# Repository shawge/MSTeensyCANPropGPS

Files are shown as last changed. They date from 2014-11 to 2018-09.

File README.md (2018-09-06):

# MSTeensyCANPropGPS
This project uses a Teensy 3.2 microcontroller to exchange data with a MegaSquirt MS3Pro engine controller over a CAN bus.

## Hardware used
* [Teensy 3.2 microcontroller](https://www.pjrc.com/store/teensy32.html)
* [Teensy Prop Shield](https://www.pjrc.com/store/prop_shield.html) connected via SPI and I2C.
  * 6-axis sensor, linear accelerometer and magnetometer
  * 3-axis angular rate gyroscope
  * Pressure/altitude and temperature
  * 2 watt audio amp
  * High speed 5V buffers for driving LEDs
  * 8MB flash
* [Adafruit Ultimate GPS](http://www.adafruit.com/products/746) connected via serial
  * Version 3, 66 channel w/ 10Hz updates
* [Waveshare CAN Transceiver](https://www.waveshare.com/sn65hvd230-can-board.htm) connected via serial
* [Color 320x240 TFT Touch Screen](https://www.pjrc.com/store/display_ili9341_touch.html) connected via SPI

## Libraries used
* [NXPMotionSense](https://github.com/PaulStoffregen/NXPMotionSense) - motion sensors
* [ILI9341_t3](https://github.com/PaulStoffregen/ILI9341_t3) - TFT
* [XPT2046_Touchscreen](https://github.com/PaulStoffregen/XPT2046_Touchscreen) - touch screen
* [FlexCAN](https://github.com/teachop/FlexCAN_Library) - CAN bus
* [TinyGPSPlus](https://github.com/mikalhart/TinyGPSPlus) - GPS
* [FastLED](https://github.com/FastLED/FastLED) - LED

## Inspiration for this project is from 
* openhoon/MSCan_Gauge
* merkur2k/MSCan_Gauge

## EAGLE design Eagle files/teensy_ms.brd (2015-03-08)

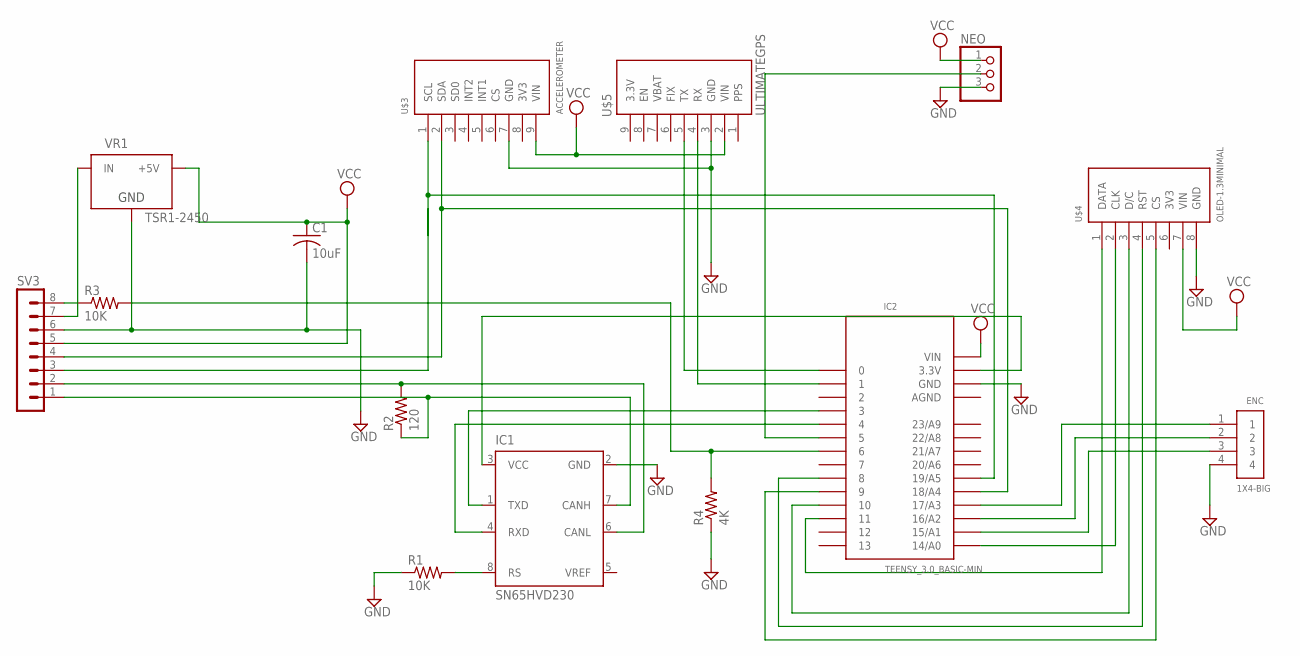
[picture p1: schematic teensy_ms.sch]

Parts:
C1: 10uF; C1206
ENC: 1X4-BIG; 1X04-BIG
IC1: SN65HVD230; SO8
IC2: TEENSY_3.0_BASIC-MIN; TEESNY_3.0_BASIC-MIN
NEO: PINHD-1X3; 1X03
R1, R3: 10K; M1206
R2: 120; M1206
R4: 4K; M1206
SV3: MA08-1
U$3: ACCELEROMETER
U$4: OLED-1.3MINIMAL; OLED-1.3-BARE
U$5: ULTIMATEGPS
VR1: TSR1-2450; TSR-1

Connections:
AGND: IC2.AGND
GND: C1.2, ENC.4, IC1.2 (GND), IC2.GND, NEO.3, R1.1, R4.1, SV3.6, U$3.7 (GND), U$4.8 (GND), U$5.3 (GND), VR1.2 (GND)
unnamed: IC1.8 (RS), R1.2
unnamed: IC1.3 (VCC), IC2.3.3V
unnamed: SV3.7, VR1.1 (IN)
unnamed: IC2.1, U$5.4 (RX)
unnamed: IC2.0, U$5.5 (TX)
unnamed: IC2.11, U$4.1 (DATA)
unnamed: IC2.14/A0, U$4.2 (CLK)
unnamed: IC2.10, U$4.3 (D/C)
unnamed: IC2.8, U$4.4 (RST)
unnamed: IC2.9, U$4.5 (CS)
unnamed: IC1.4 (RXD), IC2.4
unnamed: IC2.19/A5, SV3.3, U$3.1 (SCL)
unnamed: IC1.1 (TXD), IC2.3
unnamed: IC2.18/A4, SV3.4, U$3.2 (SDA)
unnamed: IC2.5, NEO.2
unnamed: IC1.7 (CANH), R2.1, SV3.1
unnamed: IC2.6, R3.2, R4.2
unnamed: IC1.6 (CANL), R2.2, SV3.2
unnamed: ENC.3, IC2.15/A1
unnamed: ENC.2, IC2.16/A2
unnamed: ENC.1, IC2.17/A3
unnamed: R3.1, SV3.8
VCC: C1.1, IC2.VIN, NEO.1, SV3.5, U$3.9 (VIN), U$4.7 (VIN), U$5.2 (VIN), VR1.3 (+5V)

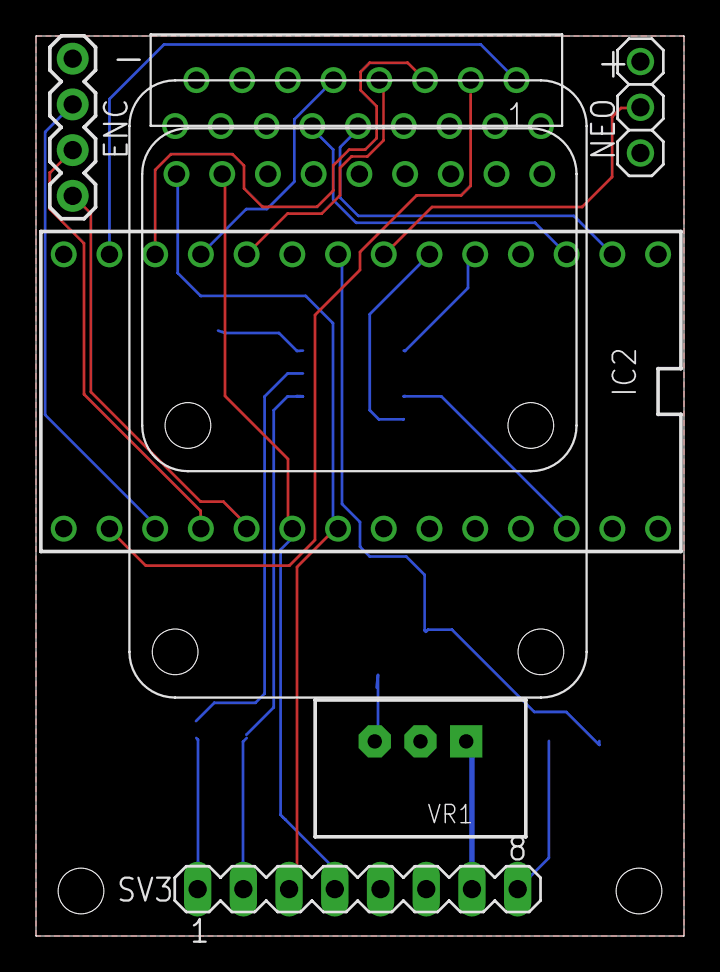
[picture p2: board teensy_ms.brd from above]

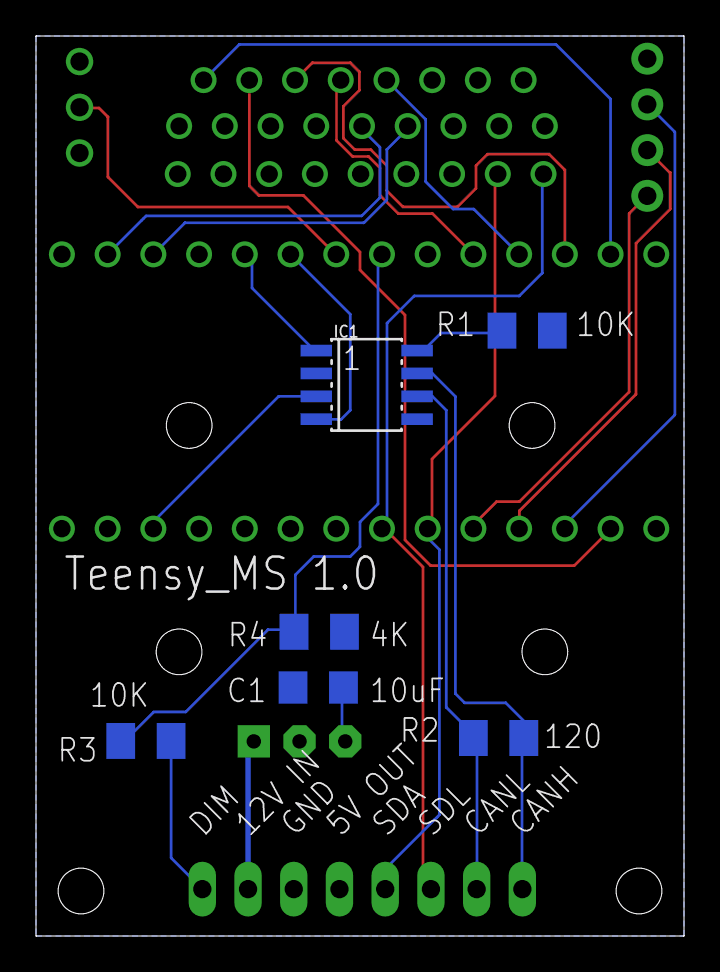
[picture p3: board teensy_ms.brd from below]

Board: 2 copper layers, 36.0 x 50.0 mm, 14 parts (6 on the bottom side), 24 nets.

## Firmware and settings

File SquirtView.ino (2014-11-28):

/*
  Although heavily modified by now to work with the Teensy and with newer Megasquirt features
  (CAN broadcasting), much of this code originally came from https://github.com/kckr/MSCan_Gauge
  Many thanks to that project, as I would not have gotten started without it.
*/

// User configuerable variables
const int myCANid = 10; // CAN ID of this unit
const int msCANid = 0; // CAN ID of the Megasquirt (should almost always be 0)
const int REVLIMIT = 6800; // soft rev limit at which to start blinking the tach gauge

#include <Metro.h>
#include <FlexCAN.h>
#include <SPI.h>
#include <Wire.h>
#include <Adafruit_GFX.h>
#include <Adafruit_SSD1306.h>
#include <Time.h>
#include <TinyGPS++.h>
TinyGPSPlus GPS;

#include <FastLED.h>
#define LEDPIN 5
#define NUMLEDS 16
CRGB leds[NUMLEDS];

#include <Encoder.h>
Encoder myEnc(7, 6); // interrupts on pin6, 7
#define RBUTTON_INT 15 // pin 15
const unsigned long debouncing_time = 150; //Debouncing Time - 150 is good, 200 is better, 250 seems worse
volatile unsigned long last_millis; //switch debouncing

#include <Adafruit_Sensor.h>
#include <Adafruit_ADXL345_U.h>
/* Assign a unique ID to this sensor at the same time */
Adafruit_ADXL345_Unified accel = Adafruit_ADXL345_Unified(12345);

// OLED display
/* Software SPI
#define OLED_MOSI   9
#define OLED_CLK   10
#define OLED_DC    11
#define OLED_CS    12
#define OLED_RESET 8
Adafruit_SSD1306 display(OLED_MOSI, OLED_CLK, OLED_DC, OLED_RESET, OLED_CS);
*/

// Hardware SPI
#define OLED_DC     10
#define OLED_CS     9
#define OLED_RESET  8
Adafruit_SSD1306 display(OLED_DC, OLED_RESET, OLED_CS);

#if (SSD1306_LCDHEIGHT != 64)
#error("Height incorrect, please fix Adafruit_SSD1306.h!");
#endif

// Metro ticks are milliseconds
Metro gpsTimer = Metro(1000); // display GPS status
Metro commTimer = Metro(1000); // display an error message if no CAN data during this interval
Metro displayTimer = Metro(100); // refresh the display at this interval
Metro ledTimer = Metro(1); // how long to flash the led upon CAN frame receive/transmit
Metro gaugeBlinkTimer = Metro(100); // blink the led ring pixels during certain conditions
boolean connectionState = false;
boolean gpsLogo = false;
boolean gaugeBlink = false;

int led = 13;
FlexCAN CANbus(500000);
static CAN_message_t txmsg,rxmsg;
static uint8_t hex[17] = "0123456789abcdef";

int rpm,ect,afr;
unsigned int txTimer,rxTimer;

//MS data vars
byte indicator[7]; // where to store indicator data
unsigned int RPM, CLT, MAP, MAT, SPKADV, BATTV, TPS, Knock, Baro, EGOc, IAC, dwell, bstduty, idle_tar;
int AFR, AFRtgt;
unsigned int MAP_HI, Knock_HI, RPM_HI, CLT_HI, MAT_HI;
int AFR_HI, AFR_LO;

//static char sprintfbuffer[2];

struct ledval {
  byte r0;
  byte g0;
  byte b0;
  byte r1;
  byte g1;
  byte b1;
  byte r2;
  byte g2;
  byte b2;
  byte r3;
  byte g3;
  byte b3;
};

const ledval ledarray[] PROGMEM = {
//r0, g0, b0, r1, g1, b1, r2, g2, b2, r3, g3, b3
  {0x0,0x5,0xFF,0x0,0x0,0x0,0x0,0x0,0x0,0x0,0x0,0x0}, //0
  {0x0,0x6,0xFE,0x0,0x0,0x0,0x0,0x0,0x0,0x0,0x0,0x0}, //1
  {0x0,0x7,0xFD,0x0,0x0,0x0,0x0,0x0,0x0,0x0,0x0,0x0}, //2
  {0x0,0x8,0xFC,0x0,0x0,0x0,0x0,0x0,0x0,0x0,0x0,0x0}, //3
  {0x0,0x9,0xFB,0x0,0x0,0x0,0x0,0x0,0x0,0x0,0x0,0x0}, //4
  {0x0,0xA,0xFA,0x0,0x0,0x0,0x0,0x0,0x0,0x0,0x0,0x0}, //5
  {0x0,0xB,0xF9,0x0,0x0,0x0,0x0,0x0,0x0,0x0,0x0,0x0}, //6
  {0x0,0xC,0xF8,0x0,0x0,0x0,0x0,0x0,0x0,0x0,0x0,0x0}, //7
  {0x0,0xD,0xF7,0x0,0x0,0x0,0x0,0x0,0x0,0x0,0x0,0x0}, //8
  {0x0,0xE,0xF6,0x0,0x0,0x0,0x0,0x0,0x0,0x0,0x0,0x0}, //9
  {0x0,0xF,0xF5,0x0,0x0,0x0,0x0,0x0,0x0,0x0,0x0,0x0}, //10
  {0x0,0x10,0xF4,0x0,0x0,0x0,0x0,0x0,0x0,0x0,0x0,0x0}, //11
  {0x0,0x11,0xF3,0x0,0x0,0x0,0x0,0x0,0x0,0x0,0x0,0x0}, //12
  {0x0,0x12,0xF2,0x0,0x0,0x0,0x0,0x0,0x0,0x0,0x0,0x0}, //13
  {0x0,0x13,0xF1,0x0,0x0,0x0,0x0,0x0,0x0,0x0,0x0,0x0}, //14
  {0x0,0x14,0xF0,0x0,0x0,0x0,0x0,0x0,0x0,0x0,0x0,0x0}, //15
  {0x0,0x15,0xEF,0x0,0x0,0x0,0x0,0x0,0x0,0x0,0x0,0x0}, //16
  {0x0,0x16,0xEE,0x0,0x0,0x0,0x0,0x0,0x0,0x0,0x0,0x0}, //17
  {0x0,0x17,0xED,0x0,0x0,0x0,0x0,0x0,0x0,0x0,0x0,0x0}, //18
  {0x0,0x18,0xEC,0x0,0x0,0x0,0x0,0x0,0x0,0x0,0x0,0x0}, //19
  {0x0,0x19,0xEB,0x0,0x0,0x0,0x0,0x0,0x0,0x0,0x0,0x0}, //20
  {0x0,0x1A,0xEA,0x0,0x0,0x0,0x0,0x0,0x0,0x0,0x0,0x0}, //21
  {0x0,0x1B,0xE9,0x0,0x0,0x0,0x0,0x0,0x0,0x0,0x0,0x0}, //22
  {0x0,0x1C,0xE8,0x0,0x0,0x0,0x0,0x0,0x0,0x0,0x0,0x0}, //23
  {0x0,0x1D,0xE7,0x0,0x0,0x0,0x0,0x0,0x0,0x0,0x0,0x0}, //24
  {0x0,0x1E,0xE6,0x0,0x0,0x0,0x0,0x0,0x0,0x0,0x0,0x0}, //25
  {0x0,0x1F,0xE5,0x0,0x0,0x0,0x0,0x0,0x0,0x0,0x0,0x0}, //26
  {0x0,0x20,0xE4,0x0,0x0,0x0,0x0,0x0,0x0,0x0,0x0,0x0}, //27
  {0x0,0x21,0xE3,0x0,0x0,0x0,0x0,0x0,0x0,0x0,0x0,0x0}, //28
  {0x0,0x22,0xE2,0x0,0x0,0x0,0x0,0x0,0x0,0x0,0x0,0x0}, //29
  {0x0,0x23,0xE1,0x0,0x0,0x0,0x0,0x0,0x0,0x0,0x0,0x0}, //30
  {0x0,0x24,0xE0,0x0,0x0,0x0,0x0,0x0,0x0,0x0,0x0,0x0}, //31
  {0x0,0x25,0xDF,0x0,0x0,0x0,0x0,0x0,0x0,0x0,0x0,0x0}, //32
  {0x0,0x26,0xDE,0x0,0x0,0x0,0x0,0x0,0x0,0x0,0x0,0x0}, //33
  {0x0,0x27,0xDD,0x0,0x0,0x1,0x0,0x0,0x0,0x0,0x0,0x0}, //34
  {0x0,0x28,0xDC,0x0,0x0,0x1,0x0,0x0,0x0,0x0,0x0,0x0}, //35
  {0x0,0x29,0xDB,0x0,0x0,0x1,0x0,0x0,0x0,0x0,0x0,0x0}, //36
  {0x0,0x2A,0xDA,0x0,0x0,0x1,0x0,0x0,0x0,0x0,0x0,0x0}, //37
  {0x0,0x2B,0xD9,0x0,0x0,0x1,0x0,0x0,0x0,0x0,0x0,0x0}, //38
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
};

const unsigned char ms_logo [] = {
  0xFF, 0xFF, 0xFF, 0xFF, 0xFF, 0xFF, 0xFF, 0x00, 0x00, 0x00, 0x00, 0x00, 0x00, 0x00, 0x00, 0x00,
  0xFF, 0xFF, 0xFF, 0xFF, 0xFF, 0xFF, 0xFF, 0x00, 0x00, 0x00, 0x00, 0x00, 0x00, 0x00, 0x00, 0x00,
  0xFF, 0xFF, 0xFF, 0xFF, 0xFF, 0xFF, 0xFF, 0x00, 0x00, 0x00, 0x00, 0x00, 0x00, 0x00, 0x00, 0x00,
  0xE0, 0x00, 0x00, 0x00, 0x00, 0x00, 0x07, 0x00, 0x00, 0x00, 0x00, 0x00, 0x00, 0x00, 0x00, 0x00,
  0xE0, 0x00, 0x00, 0x00, 0x00, 0x00, 0x07, 0x00, 0x00, 0x00, 0x00, 0x00, 0x00, 0x00, 0x00, 0x00,
  0xE0, 0x00, 0x00, 0x00, 0x00, 0x00, 0x07, 0x00, 0x00, 0x00, 0x00, 0x00, 0x00, 0x00, 0x00, 0x00,
  0xE7, 0xFF, 0xFF, 0xFF, 0xFF, 0xFF, 0xE7, 0x00, 0x00, 0x00, 0x00, 0x00, 0x00, 0x00, 0x00, 0x00,
  0xE7, 0xFF, 0xFF, 0xFF, 0xFF, 0xFF, 0xE7, 0x00, 0x00, 0x00, 0x00, 0x00, 0x00, 0x00, 0x00, 0x00,
  0xE7, 0xFF, 0xFF, 0xFF, 0xFF, 0xFF, 0xE7, 0x00, 0x00, 0x00, 0x00, 0x00, 0x00, 0x00, 0x00, 0x00,
  0xE7, 0xFF, 0xFF, 0xFF, 0xFF, 0xFF, 0xC7, 0x00, 0x00, 0x00, 0x00, 0x00, 0x00, 0x00, 0x00, 0x00,
  0xE7, 0xFF, 0xFF, 0xFF, 0xFF, 0xFF, 0x07, 0x00, 0x3E, 0x78, 0x00, 0x00, 0x00, 0x00, 0x00, 0x00,
  0xE7, 0xFF, 0xFF, 0xFF, 0xFF, 0xFC, 0x07, 0x00, 0x3F, 0xFE, 0x00, 0x00, 0x00, 0x00, 0x00, 0x00,
  0xE7, 0xFF, 0xFF, 0xFF, 0xFF, 0xF8, 0x07, 0x00, 0x7F, 0xFE, 0x00, 0x00, 0x00, 0x00, 0x00, 0x00,
  0xE7, 0xFF, 0xFF, 0xFF, 0xFF, 0xE0, 0x07, 0x00, 0x73, 0xCE, 0x00, 0x00, 0x00, 0x00, 0x00, 0x00,
  0xE7, 0xFF, 0xFF, 0xFF, 0xFF, 0xC0, 0xE7, 0x00, 0x63, 0x86, 0x0F, 0x87, 0xE0, 0x38, 0x00, 0x00,
  0xE7, 0xFF, 0xFF, 0xFF, 0xFE, 0x03, 0xE7, 0x00, 0x61, 0x86, 0x3F, 0x8F, 0xF0, 0x3C, 0x00, 0x00,
  0xE7, 0xFF, 0xFF, 0xFF, 0xF8, 0x0F, 0xC7, 0x00, 0x61, 0x86, 0x7F, 0x9F, 0xF8, 0x7C, 0x00, 0x00,
  0xE1, 0xFF, 0xFF, 0xFF, 0xF0, 0x3F, 0x07, 0x00, 0x61, 0x86, 0x78, 0x1E, 0x38, 0x7E, 0x00, 0x00,
  0xE0, 0x7F, 0xFF, 0xFF, 0x80, 0xF8, 0x07, 0x00, 0x61, 0x86, 0xE0, 0x38, 0x38, 0x6E, 0x00, 0x00,
  0xE0, 0x1F, 0xFF, 0xFF, 0x07, 0xE0, 0x07, 0x00, 0x61, 0x86, 0xE0, 0x38, 0x00, 0xEE, 0x00, 0x00,
  0xE0, 0x07, 0xFF, 0xFC, 0x1F, 0x00, 0x07, 0x00, 0x61, 0x86, 0xFE, 0x30, 0xFC, 0xFE, 0x00, 0x00,
  0xE0, 0x01, 0xFF, 0xF0, 0x78, 0x00, 0x07, 0x00, 0x61, 0x86, 0xFE, 0x30, 0xFC, 0xFF, 0x00, 0x00,
  0xE0, 0x00, 0x7F, 0xE1, 0xE0, 0x01, 0xE7, 0x00, 0x61, 0x86, 0xFE, 0x30, 0xFC, 0xFF, 0x00, 0x00,
  0xE0, 0x00, 0x1F, 0x86, 0x00, 0x1F, 0xE7, 0x00, 0x61, 0x86, 0xC0, 0x30, 0xFD, 0xFF, 0x00, 0x00,
  0xE0, 0x00, 0x0E, 0x18, 0x00, 0xFF, 0xE7, 0x00, 0x61, 0x86, 0xE0, 0x38, 0x1D, 0xC3, 0x80, 0x00,
  0xE0, 0x00, 0x08, 0xC0, 0x0F, 0xFC, 0x07, 0x00, 0x61, 0x86, 0xE0, 0x38, 0x39, 0x83, 0x80, 0x00,
  0xE0, 0x00, 0x23, 0x01, 0xFF, 0x00, 0x07, 0x00, 0x61, 0x86, 0x70, 0x1E, 0x7B, 0x83, 0x80, 0x00,
  0xE0, 0x00, 0x88, 0x1F, 0xE0, 0x00, 0x07, 0x00, 0x61, 0x86, 0x7F, 0xDF, 0xFB, 0x83, 0x80, 0x00,
  0xE0, 0x01, 0x60, 0xF0, 0x00, 0x00, 0x07, 0x00, 0x61, 0x86, 0x3F, 0xCF, 0xF3, 0x81, 0x80, 0x00,
  0xE0, 0x00, 0x0C, 0x00, 0x00, 0x00, 0x07, 0x00, 0x00, 0x00, 0x00, 0x00, 0x00, 0x00, 0x00, 0x00,
  0xE0, 0x08, 0x40, 0x00, 0x03, 0xFF, 0xE7, 0x00, 0x00, 0x00, 0x00, 0x00, 0x00, 0x00, 0x00, 0x00,
  0xE0, 0x18, 0x01, 0xFF, 0xFF, 0xFF, 0xE7, 0x00, 0x00, 0x00, 0x00, 0x00, 0x00, 0x00, 0x00, 0x00,
  0xE0, 0x1C, 0x00, 0x1F, 0xFF, 0xFF, 0xE7, 0x00, 0x00, 0x00, 0x00, 0x00, 0x00, 0x00, 0x00, 0x00,
  0xE0, 0x02, 0x00, 0x00, 0x00, 0x07, 0xC7, 0x00, 0x00, 0x00, 0x00, 0x00, 0x00, 0x00, 0x00, 0x00,
  0xE0, 0x00, 0x8F, 0x00, 0x00, 0x00, 0x07, 0x00, 0x1F, 0xF0, 0x00, 0x00, 0x00, 0x00, 0x00, 0x00,
  0xE0, 0x01, 0x00, 0xFC, 0x00, 0x00, 0x07, 0x00, 0x3F, 0xF0, 0x00, 0x00, 0x00, 0x00, 0x00, 0x00,
  0xE0, 0x00, 0x48, 0x07, 0xF0, 0x00, 0x07, 0x00, 0x7F, 0xF0, 0x00, 0x00, 0x00, 0x00, 0x00, 0x00,
  0xE0, 0x00, 0x23, 0x00, 0xFF, 0xE0, 0x07, 0x00, 0x70, 0x00, 0x00, 0x00, 0x00, 0x00, 0x00, 0x00,
  0xE0, 0x00, 0x08, 0x60, 0x0F, 0xFF, 0x07, 0x00, 0x60, 0x00, 0x3C, 0x18, 0x6C, 0xF9, 0xFF, 0x00,
  0xE0, 0x00, 0x0E, 0x18, 0x00, 0x7F, 0xE7, 0x00, 0x60, 0x00, 0xFE, 0x18, 0x6C, 0xFD, 0xFF, 0x00,
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
};

const unsigned char gps [] = {
  0x00, 0x10, 0x00, 0x38, 0x00, 0x7C, 0x00, 0xF8, 0x01, 0xF0, 0x05, 0xE0, 0x00, 0xC0, 0x0C, 0x00,
  0x1E, 0x90, 0x3E, 0x12, 0x7C, 0x24, 0xF8, 0xC4, 0x70, 0x08, 0x20, 0x30, 0x00, 0x40, 0x00, 0x00
};

struct MSDataObject {
  char name[10]; // length tbd
  byte block; // max val 32?
  unsigned int offset; // max val?
  byte reqbytes; // max val 8
  byte mult; // does this need to be * 0.1 ?
};

const MSDataObject MSData[] PROGMEM = {
// string,  block, offset, reqbytes, mult, div
  {"RPM",     7,   6,  2,    0   }, // 0
  {"AFR",     7,  252, 1,    0   }, // 1
  {"CLT",     7,  22,  2,    1   }, // 2
  {"MAP",     7,  18,  2,    1   }, // 3
  {"MAT",     7,  20,  2,    1   }, // 4
  {"SPKADV",  7,   8,  2,    1   }, // 5
  {"BATTV",   7,  26,  2,    1   }, // 6
  {"TPS",     7,  24,  2,    1   }, // 7
  {"Knock",   7,  32,  2,    1   }, // 8
  {"Baro",    7,  16,  2,    1   }, // 9
  {"EGOc",    7,  34,  2,    1   }, // 10
  {"IAC",     7,  54,  2,    0   }, // 11 -- this was GFC's to 49 / 125
  {"dwell",   7,  62,  2,    1   }, // 12
  {"bstduty", 7,  39,  1,    0   }, // 13 boost duty cycle
  {"idletar", 7, 380,  2,    0   }, // 14
  {"AFRtgt",  7,  12,  1,    1   }, // 15
};

struct MSDataBinaryObject {
  char name[14];
  byte sbyte;
  byte bitp;
};

const MSDataBinaryObject MSDataBin[] PROGMEM = {
// "1234567890"
//"name", indicator byte, bit position
//0 engine - block 7 offset 11
  {"Ready",            0,  0 },
  {"Crank",            0,  1 },
  {"ASE",              0,  2 },
  {"WUE",              0,  3 },
  {"TPS acc",          0,  4 },
  {"TPS dec",          0,  5 },
  {"MAP acc",          0,  6 },
  {"MAP dec",          0,  7 },
//1 status1 - block7 offset 78
  {"Need Burn",        1,  0,},
  {"Data Lost",        1,  1 },
  {"Config Error",     1,  2 },
  {"Synced",           1,  3 },
  {"VE1/2",            1,  5 },
  {"SPK1/2",           1,  6 },
  {"Full-sync",        1,  7 },
//2 status2 - block 7 offset 79
  {"N2O 1",            2,  0 },
  {"N2O 2",            2,  1 },
  {"Rev lim",          2,  2 },
  {"Launch",           2,  2 },
  {"Flat shift",       2,  4 },
  {"Spark cut",        2,  5 },
  {"Over boost",       2,  6 },
  {"CL Idle",          2,  7 },
//3 status3 - block 7 offset 80
  {"Fuel cut",         3,  0 },
//{"T-log",            3,  1 },
//{"3 step",           3,  2 },
//{"Test mode",        3,  3 },
//{"3 step",           3,  4 },
  {"Soft limit",       3,  5 },
//{"Bike shift",       3,  6 },
  {"Launch",           3,  7 },
//4 check engine lamps - block 7 offset 425
  {"cel_map",          4,  0 },
  {"cel_mat",          4,  1 },
  {"cel_clt",          4,  2 },
  {"cel_tps",          4,  3 },
  {"cel_batt",         4,  4 },
  {"cel_afr0",         4,  5 },
  {"cel_sync",         4,  6 },
  {"cel_egt",          4,  7 },
//5 port status - block 7 offset 70
  {"port0",            5,  0 },
  {"port1",            5,  1 },
  {"port2",            5,  2 },
  {"port3",            5,  3 },
  {"port4",            5,  4 },
  {"port5",            5,  5 },
  {"port6",            5,  6 },
//6 status6 - block 7 offset 233
  {"EGT warn",         6,  0 },
  {"EGT shutdown",     6,  1 },
  {"AFR warn",         6,  2 },
  {"AFR shutdown",     6,  3 },
  {"Idle VE",          6,  4 },
  {"Idle VE",          6,  5 },
  {"Fan",              6,  6 },
//7 status7 - block 7 offset 351
  {"Knock",            7,  4 },
  {"AC",               7,  5 },
};

long R_index = 0; // for rotary encoder
byte B_index = 0; // Button increment
byte M_index = 0; // Menu increment
byte S_index = 0; // Select increment

byte neo_brightness = 4;
byte g_textsize = 1;
char tempchars[11];

// -------------------------------------------------------------
static void hexDump(uint8_t dumpLen, uint8_t *bytePtr) {
  uint8_t working;
  while( dumpLen-- ) {
    working = *bytePtr++;
    Serial.write( hex[ working>>4 ] );
    Serial.write( hex[ working&15 ] );
  }
  //Serial.write('\r');
  //Serial.write('\n');
}
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
void loop(void) {
  if (ledTimer.check() && digitalRead(led)) {
    digitalWrite(led, 0);
    ledTimer.reset();
  }
  if (gaugeBlinkTimer.check()) {
    gaugeBlink = gaugeBlink ^ 1;
    gaugeBlinkTimer.reset();
  }

  // Handle GPS data

  bool nmeaReceived = false;
  while (!nmeaReceived && (Serial1.available() > 0)) {
    nmeaReceived = GPS.encode(Serial1.read());
  }

  if (GPS.location.isUpdated()) { // set local clock from GPS
    if (GPS.time.age() < 500) {
      setTime(GPS.time.hour(), GPS.time.minute(), GPS.time.second(), GPS.date.day(), GPS.date.month(), GPS.date.year());
      adjustTime(-8 * SECS_PER_HOUR);
    }
  }
  if (commTimer.check()) { // see if we have gotten any CAN messages in the last second. display an error if not
    clear();
    display.setTextSize(1);
    display.setTextColor(WHITE);
    display.setCursor(0,56);
    display.println("Waiting for data...");
    display.setCursor(0,0);
    display.println(GPS.time.age());
    display.println(GPS.location.isUpdated());
    display.println(GPS.location.lat(),5);
    display.println(GPS.location.lng(),5);
    display.display();
    for(int i=0; i<16; i++) {
      leds[i].setRGB(0,0,0); // initialize led ring
    }
    FastLED.show();
    commTimer.reset();
    connectionState = false;
  }
  if (gpsTimer.check()) {
    if (GPS.satellites.value()) {
      gpsLogo = true;
    } else {
      gpsLogo = gpsLogo ^ 1;
    }
    gpsTimer.reset();
  }
  /* touchRead() can take up to 5ms to do its thing, so this is useless..
  if (0 && displayTimer.check()) { // read the buttons
    for (int i=0; i<3; i++) {
      if (touchRead(15 + i) - buttons[i].init > 1000) { // button is pressed
        if (buttons[i].last == 0) { // button was not pressed during last loop, register a "click"
          switch (i) {
            case 0: R_index++; break;
            case 1: ISR_debounce(); break;
            case 2: R_index--; break;
          }
        }
        buttons[i].last = 1;
      } else {
        buttons[i].last = 0;
      }
    }
  }
  */
  if (connectionState && displayTimer.check()) { // main display routine
    R_index=myEnc.read()/4;
    if (! value_oob() ) {
      switch (B_index) {
      case 0:
        gauge_vitals();
        break;
      case 1:
        gauge_single();
        break;
      case 2:
        gauge_histogram();
        break;
      case 3:
        gauge_debug();
        break;
      //case 4:
      //  gauge_danger();
      //  break;
      case 4:
        gauge_menu();
        break;
        //default: write_gauge_3(); break;
      }
      write_neopixel();

    } else {
      gauge_warning();
      FastLED.show();
    }
    display.display();
    displayTimer.reset();
  }

  // handle received CAN frames
  if ( CANbus.read(rxmsg) ) {
    commTimer.reset();
    connectionState = true;
    ledBlink();
    switch (rxmsg.id) { // ID's 1520+ are Megasquirt CAN broadcast frames
    case 1520: // 0
      RPM=(int)(word(rxmsg.buf[6], rxmsg.buf[7]));
      break;
    case 1521: // 1
      SPKADV=(int)(word(rxmsg.buf[0], rxmsg.buf[1]));
      indicator[0]=rxmsg.buf[3]; // engine
      AFRtgt=(int)(word(0x00, rxmsg.buf[4]));
      break;
    case 1522: // 2
      Baro=(int)(word(rxmsg.buf[0], rxmsg.buf[1]));
      MAP=(int)(word(rxmsg.buf[2], rxmsg.buf[3]));
      MAT=(int)(word(rxmsg.buf[4], rxmsg.buf[5]));
      CLT=(int)(word(rxmsg.buf[6], rxmsg.buf[7]));
      break;
    case 1523: // 3
      TPS=(int)(word(rxmsg.buf[0], rxmsg.buf[1]));
      BATTV=(int)(word(rxmsg.buf[2], rxmsg.buf[3]));
      break;
    case 1524: // 4
      Knock=(int)(word(rxmsg.buf[0], rxmsg.buf[1]));
      EGOc=(int)(word(rxmsg.buf[2], rxmsg.buf[3]));
      break;
    case 1526: // 6
      IAC=(int)(word(rxmsg.buf[6], rxmsg.buf[7])); //IAC = (IAC * 49) / 125;
    case 1529: // 9
      dwell=(int)(word(rxmsg.buf[4], rxmsg.buf[5]));
      break;
    case 1530: // 10
      indicator[1]=rxmsg.buf[0]; // status 1
      indicator[2]=rxmsg.buf[1]; // status 2
      indicator[3]=rxmsg.buf[2]; // status 3
      indicator[6]=rxmsg.buf[6]; // status 6
      indicator[7]=rxmsg.buf[7]; // status 7
      break;
    case 1537: // 17
      bstduty=(int)(word(rxmsg.buf[4], rxmsg.buf[5]));
      break;
    case 1548: // 28
      idle_tar=(int)(word(rxmsg.buf[0], rxmsg.buf[1]));
      break;
    case 1551: // 31
      AFR=(int)(word(0x00, rxmsg.buf[0]));
      //afr = rxmsg.buf[0];
      break;
    case 1574: // 54
      indicator[4]=rxmsg.buf[2]; // cel
      break;
    default: // not a broadcast packet
      if (rxmsg.ext) { //assume this is a normal Megasquirt CAN protocol packet and decode the header
        rxmsg_id.i = rxmsg.id;
        if (rxmsg_id.values.to_id == myCANid) { // is this being sent to us?
          switch (rxmsg_id.values.msg_type) {
          case 1: // MSG_REQ - request data
            // the data required for the MSG_RSP header is packed into the first 3 data bytes
            msg_req_data.bytes.b0 = rxmsg.buf[0];
            msg_req_data.bytes.b1 = rxmsg.buf[1];
            msg_req_data.bytes.b2 = rxmsg.buf[2];
            // Create the tx packet header
            txmsg_id.values.msg_type = 2; // MSG_RSP
            txmsg_id.values.to_id = msCANid; // Megasquirt CAN ID should normally be 0
            txmsg_id.values.from_id = myCANid;
            txmsg_id.values.block = msg_req_data.values.varblk;
            txmsg_id.values.offset = msg_req_data.values.varoffset;
            txmsg.ext = 1;
            txmsg.id = txmsg_id.i;
            txmsg.len = 8;
            // Use the same block and offset as JBPerf IO expander board for compatibility reasons
            // Docs at http://www.jbperf.com/io_extender/firmware/0_1_2/io_extender.ini (or latest version)
            if (rxmsg_id.values.block == 7 && rxmsg_id.values.offset == 110) { // realtime clock
              /*
                 rtc_sec          = scalar, U08,  110, "", 1,0
                 rtc_min          = scalar, U08,  111, "", 1,0
                 rtc_hour         = scalar, U08,  112, "", 1,0
                 rtc_day          = scalar, U08,  113, "", 1,0 // not sure what "day" means. seems to be ignored...
                 rtc_date         = scalar, U08,  114, "", 1,0
                 rtc_month        = scalar, U08,  115, "", 1,0
                 rtc_year         = scalar, U16,  116, "", 1,0
              */
              if (timeStatus() == timeSet) { // only return clock info if the local clock has actually been set (via GPS or RTC)
                txmsg.buf[0] = second();
                txmsg.buf[1] = minute();
                txmsg.buf[2] = hour();
                txmsg.buf[3] = 0;
                txmsg.buf[4] = day();
                txmsg.buf[5] = month();
                txmsg.buf[6] = year() / 256;
                txmsg.buf[7] = year() % 256;
                // send the message!
                CANbus.write(txmsg);
              }
            } else if (rxmsg_id.values.block == 7 && rxmsg_id.values.offset == 128) { // gps1
              /*
                 gps_latdeg       = scalar, S08,  128, "", 1,0
                 gps_latmin       = scalar, U08,  129, "", 1,0
                 gps_latmmin      = scalar, U16,  130, "", 1,0
                 gps_londeg       = scalar, U08,  132, "", 1,0
                 gps_lonmin       = scalar, U08,  133, "", 1,0
                 gps_lonmmin      = scalar, U16,  134, "", 1,0
              */
              signed char latdeg;
              unsigned char latmin,lonmin,londeg;
              unsigned int latmmin,lonmmin;
              double intpart;
              latdeg, londeg, latmin, lonmin, latmmin, lonmmin = 0;
              latdeg = GPS.location.rawLat().deg;
              latmin = (GPS.location.lat()-GPS.location.rawLat().deg)*60;
              latmmin = ((GPS.location.rawLat().billionths * 3 / 50000) - latmin * 1000) * 10;
              londeg = GPS.location.rawLng().deg;
              lonmin = modf(abs(GPS.location.lng()),&intpart)*60,3;
              lonmmin = ((GPS.location.rawLng().billionths * 3 / 50000) - lonmin * 1000) * 10;
              txmsg.buf[0] = latdeg;
              txmsg.buf[1] = latmin;
              txmsg.buf[2] = latmmin / 256;
              txmsg.buf[3] = latmmin % 256;
              txmsg.buf[4] = londeg;
              txmsg.buf[5] = lonmin;
              txmsg.buf[6] = lonmmin / 256;
              txmsg.buf[7] = lonmmin % 256;
              // send the message!
              CANbus.write(txmsg);
            } else if (rxmsg_id.values.block == 7 && rxmsg_id.values.offset == 136) { // gps2
              /*
                 gps_lonEW        = scalar, U08,  136, "", 1,0 // bit 0 = E/W
                 gps_altk         = scalar, S08,  137, "", 1,0
                 gps_altm         = scalar, S16,  138, "", 0.1,0
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

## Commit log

2014-11-08 Updated code to work with Teensy 3.1. Neopixel ring has not been tested. The rotary encoder has no interrupt handler yet and has not been tested. There is work in progress for sending back to the MS 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
2014-11-09 Updates for RTC, accelerometer and GPS
    RTC now works (with hardcoded data). Untested code for GPS and
    accelerometer data.
2014-11-09 Accelerometer data now working
    There is (not yet) any way to directly transfer accelerometer data
    digitally as it is assumed to be an analog device, thus it will be
    emulated on CAN ADC 1-3.
2014-11-11 Switch to hardware SPI, rotary encoder now working, use local clock
2014-11-15 Add GPS and accelerometer support
    Not all GPS values have been verified yet, those that require movement
    have not.
2014-11-24 Fixed incorrect GPS math
    [SquirtView.ino]
2014-11-28 Switch from Neopixel to FastLED library
2014-11-28 Fixes and tweaks for LED ring
    [SquirtView.ino]
2015-03-08 Add PCB files and complete BOM
    [teensy_ms.brd, teensy_ms.sch]
